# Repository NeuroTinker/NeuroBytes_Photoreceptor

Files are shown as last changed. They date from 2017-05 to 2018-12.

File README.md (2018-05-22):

# NeuroBytes Rod Photoreceptor
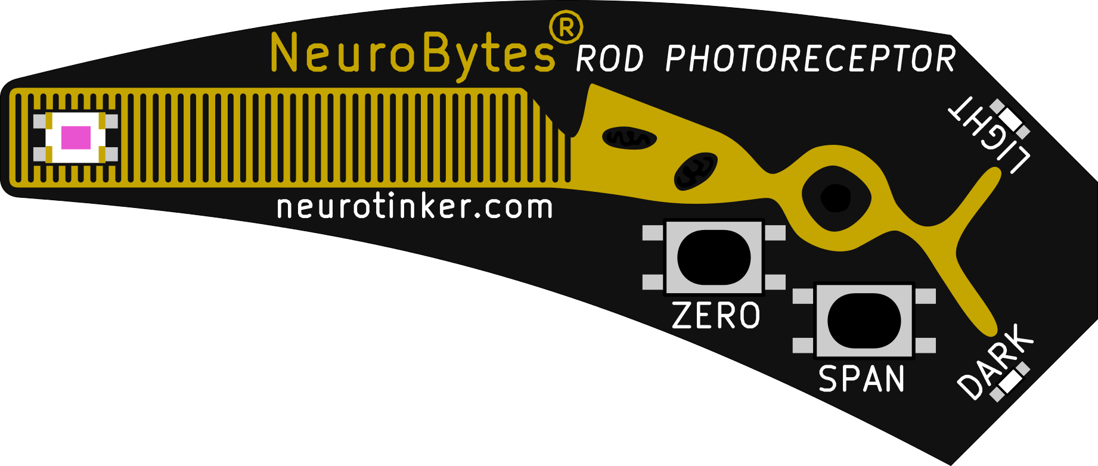
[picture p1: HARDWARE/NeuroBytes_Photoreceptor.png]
NeuroBytes Rod Photoreceptor PCB front

The NeuroBytes Rod Photoreceptor is an open-source hardware neuron simulator designed and sold by [NeuroTinker, LLC](http://www.neurotinker.com/). 

All NeuroBytes products are based on the ST32L0x series of ARM Cortex-M0+ 32-bit microcontrollers. The boards were designed in KiCad and Inkscape and are released under the terms of the Creative Commons Attribution-ShareAlike 4.0 license, available here: http://creativecommons.org/licenses/by-sa/4.0/. The NeuroBytes Rod Photoreceptor is Certified Open Source Hardware as defined by [OSHWA](https://www.oshwa.org), certification number US000108.


OSHWA Certification

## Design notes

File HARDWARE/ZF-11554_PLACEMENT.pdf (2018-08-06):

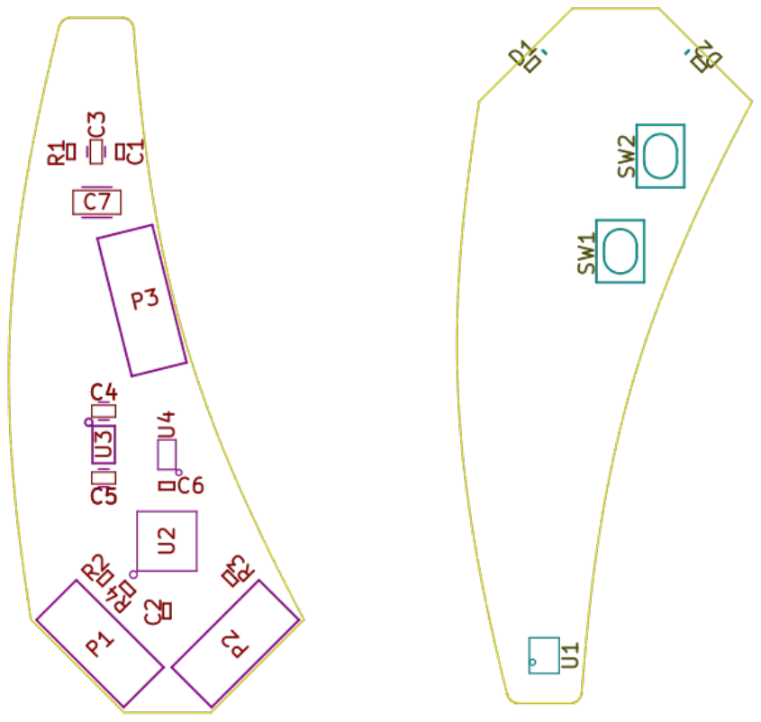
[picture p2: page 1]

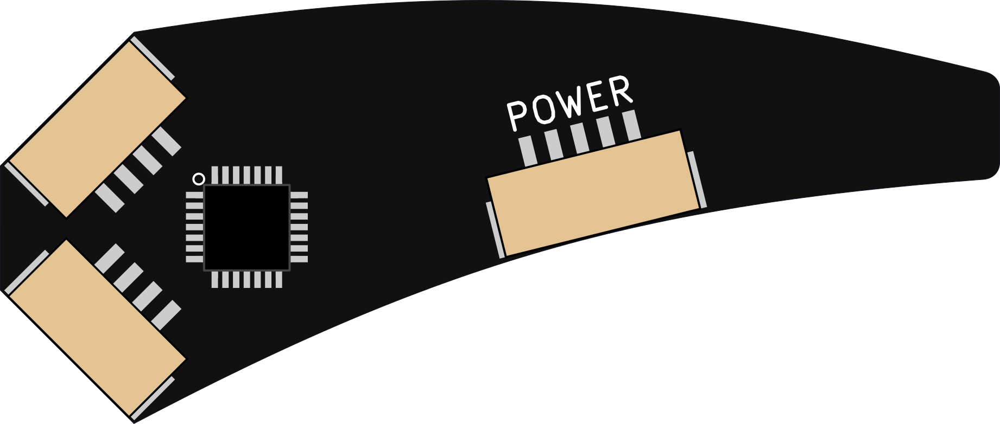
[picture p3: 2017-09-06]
HARDWARE/NeuroBytes_Photoreceptor_back.png

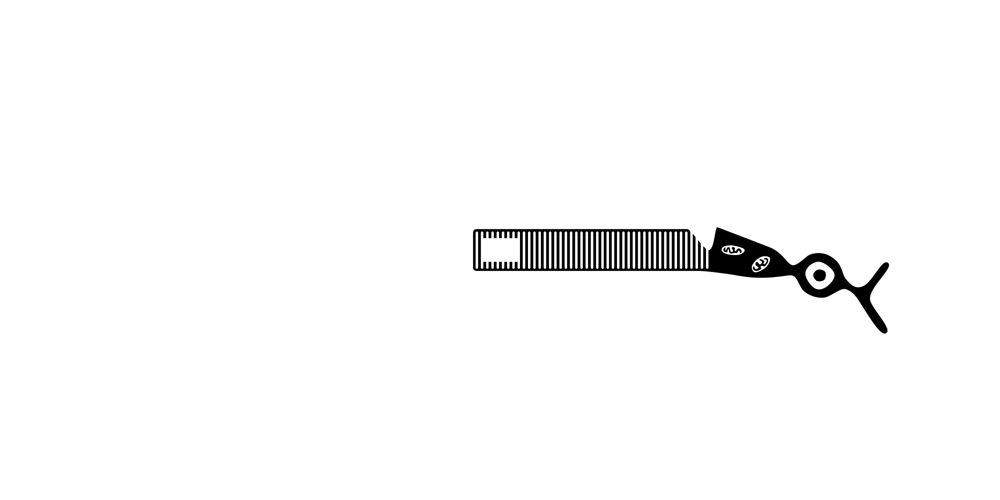
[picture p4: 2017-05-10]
HARDWARE/copper.png

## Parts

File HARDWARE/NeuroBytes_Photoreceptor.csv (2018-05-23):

Ref | Qty | Value | Link | Mfr | Mfr Part # | Package | RoHS | Subs Allowed
C4 C5 C3 | 3 | 1u | https://www.digikey.com/product-detail/en/taiyo-yuden/LMK107B7105KA-T/587-1242-2-ND/930594 | Taiyo Yuden | LMK107B7105KA-T | C0603 | Yes | Yes
C2 C6 C1 | 3 | 0u1 | https://www.digikey.com/product-detail/en/taiyo-yuden/LMK105BJ104KV-F/587-1227-2-ND/930579 | Taiyo Yuden | LMK105BJ104KV-F | C0402 | Yes | Yes
C7 | 1 | 10u | https://www.digikey.com/product-detail/en/taiyo-yuden/EMK316B7106KL-TD/587-2395-2-ND/2178914 | Taiyo Yuden | EMK316B7106KL-TD | C1206 | Yes | Yes
D1 D2 | 2 | LED | https://www.digikey.com/product-detail/en/rohm-semiconductor/SCMP13WBC8W1/846-1111-2-ND/3973663 | Rohm Semiconductor | SCMP13WBC8W1 | 2SMD | Yes | No
P1 P2 | 2 | JST_GH_4-POS | https://www.digikey.com/product-detail/en/jst-sales-america-inc/SM04B-GHS-TB-LF-SN/455-1566-2-ND/807788 | JST | SM04B-GHS-TB(LF)(SN) | SMT | Yes | No
P3 | 1 | JST_GH_5-pos | https://www.digikey.com/product-detail/en/jst-sales-america-inc/SM05B-GHS-TB-LF-SN/455-1567-2-ND/807789 | JST | SM05B-GHS-TB(LF)(SN) | SMT | Yes | No
R2 R3 | 2 | 10 | https://www.digikey.com/product-detail/en/yageo/RC0402FR-0710RL/311-10.0LRTR-ND/726524 | Yageo | RC0402FR-0710RL | R0402 | Yes | Yes
R1 | 1 | 10k | https://www.digikey.com/product-detail/en/yageo/RC0402FR-0710KL/311-10.0KLRTR-ND/726523 | Yageo | RC0402FR-0710KL | R0402 | Yes | Yes
R4 | 1 | JMP | https://www.digikey.com/product-detail/en/yageo/RC0402JR-070RL/311-0.0JRTR-ND/726406 | Yageo | RC0402JR-070RL | R0402 | Yes | Yes
SW2 SW1 | 2 | SW_PB_4term | https://www.digikey.com/product-detail/en/c-k/PTS810-SJM-250-SMTR-LFS/CKN10502TR-ND/4176610 | C&K | PTS810 SJM 250 SMTR LFS | 4SMD | Yes | No
U2 | 1 | STM32L011Gx | http://www.mouser.com/ProductDetail/STMicroelectronics/STM32L011G4U6/ | ST Microelectronics | STM32L011G4U6 | UFQFPN28 | Yes | No
U3 | 1 | 3v3 LDO | https://www.digikey.com/product-detail/en/on-semiconductor/NCP114BSN330T1G/NCP114BSN330T1GOSTR-ND/6560606 | ON Semiconductor | NCP114BSN330T1G | SOT23-5L | Yes | Yes
U1 | 1 | APDS9007 | https://www.digikey.com/product-detail/en/broadcom-limited/APDS-9007-020/516-1719-2-ND/1785429 | Broadcom | APDS-9007-020 | 6SMD | Yes | No
U4 | 1 | RClamp0503F | https://www.digikey.com/product-detail/en/semtech-corporation/RCLAMP0503F.TCT/RCLAMP0503F.TCTTR-ND/5113629 | Semtech Corporation | RCLAMP0503F.TCT | 5-TSSOP | Yes | No
BOM made with KICAD_BOM_WIZARD (https://github.com/HashDefineElectronics/KiCad_BOM_Wizard.git)
Generated Wed 23 May 2018 05:14:28 PM CDT

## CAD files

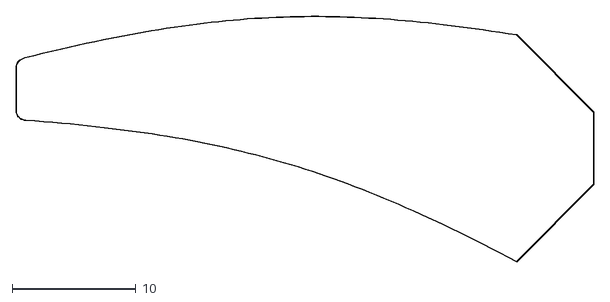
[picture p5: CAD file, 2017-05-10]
HARDWARE/NeuroBytes_Photoreceptor.dxf
46.8 x 19.8

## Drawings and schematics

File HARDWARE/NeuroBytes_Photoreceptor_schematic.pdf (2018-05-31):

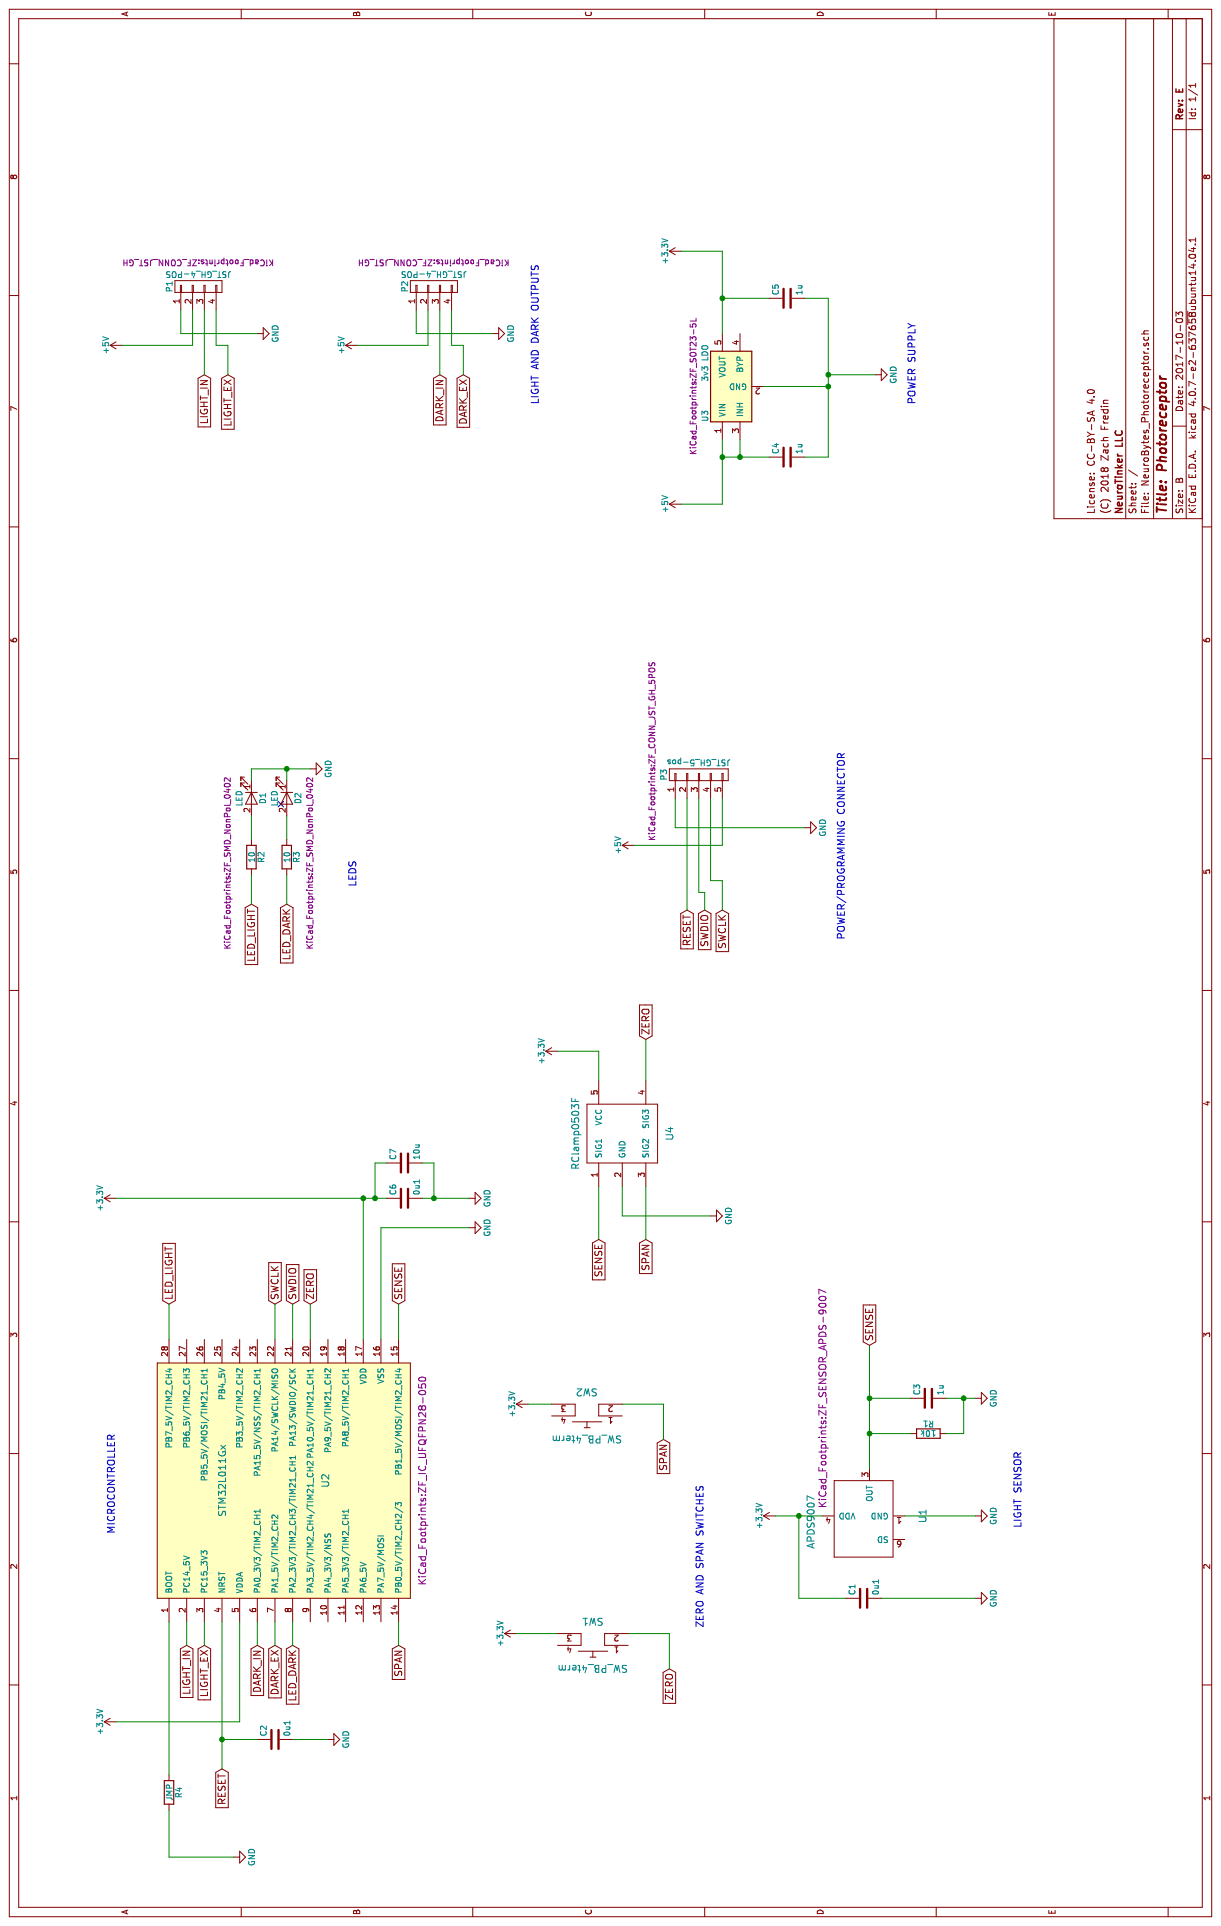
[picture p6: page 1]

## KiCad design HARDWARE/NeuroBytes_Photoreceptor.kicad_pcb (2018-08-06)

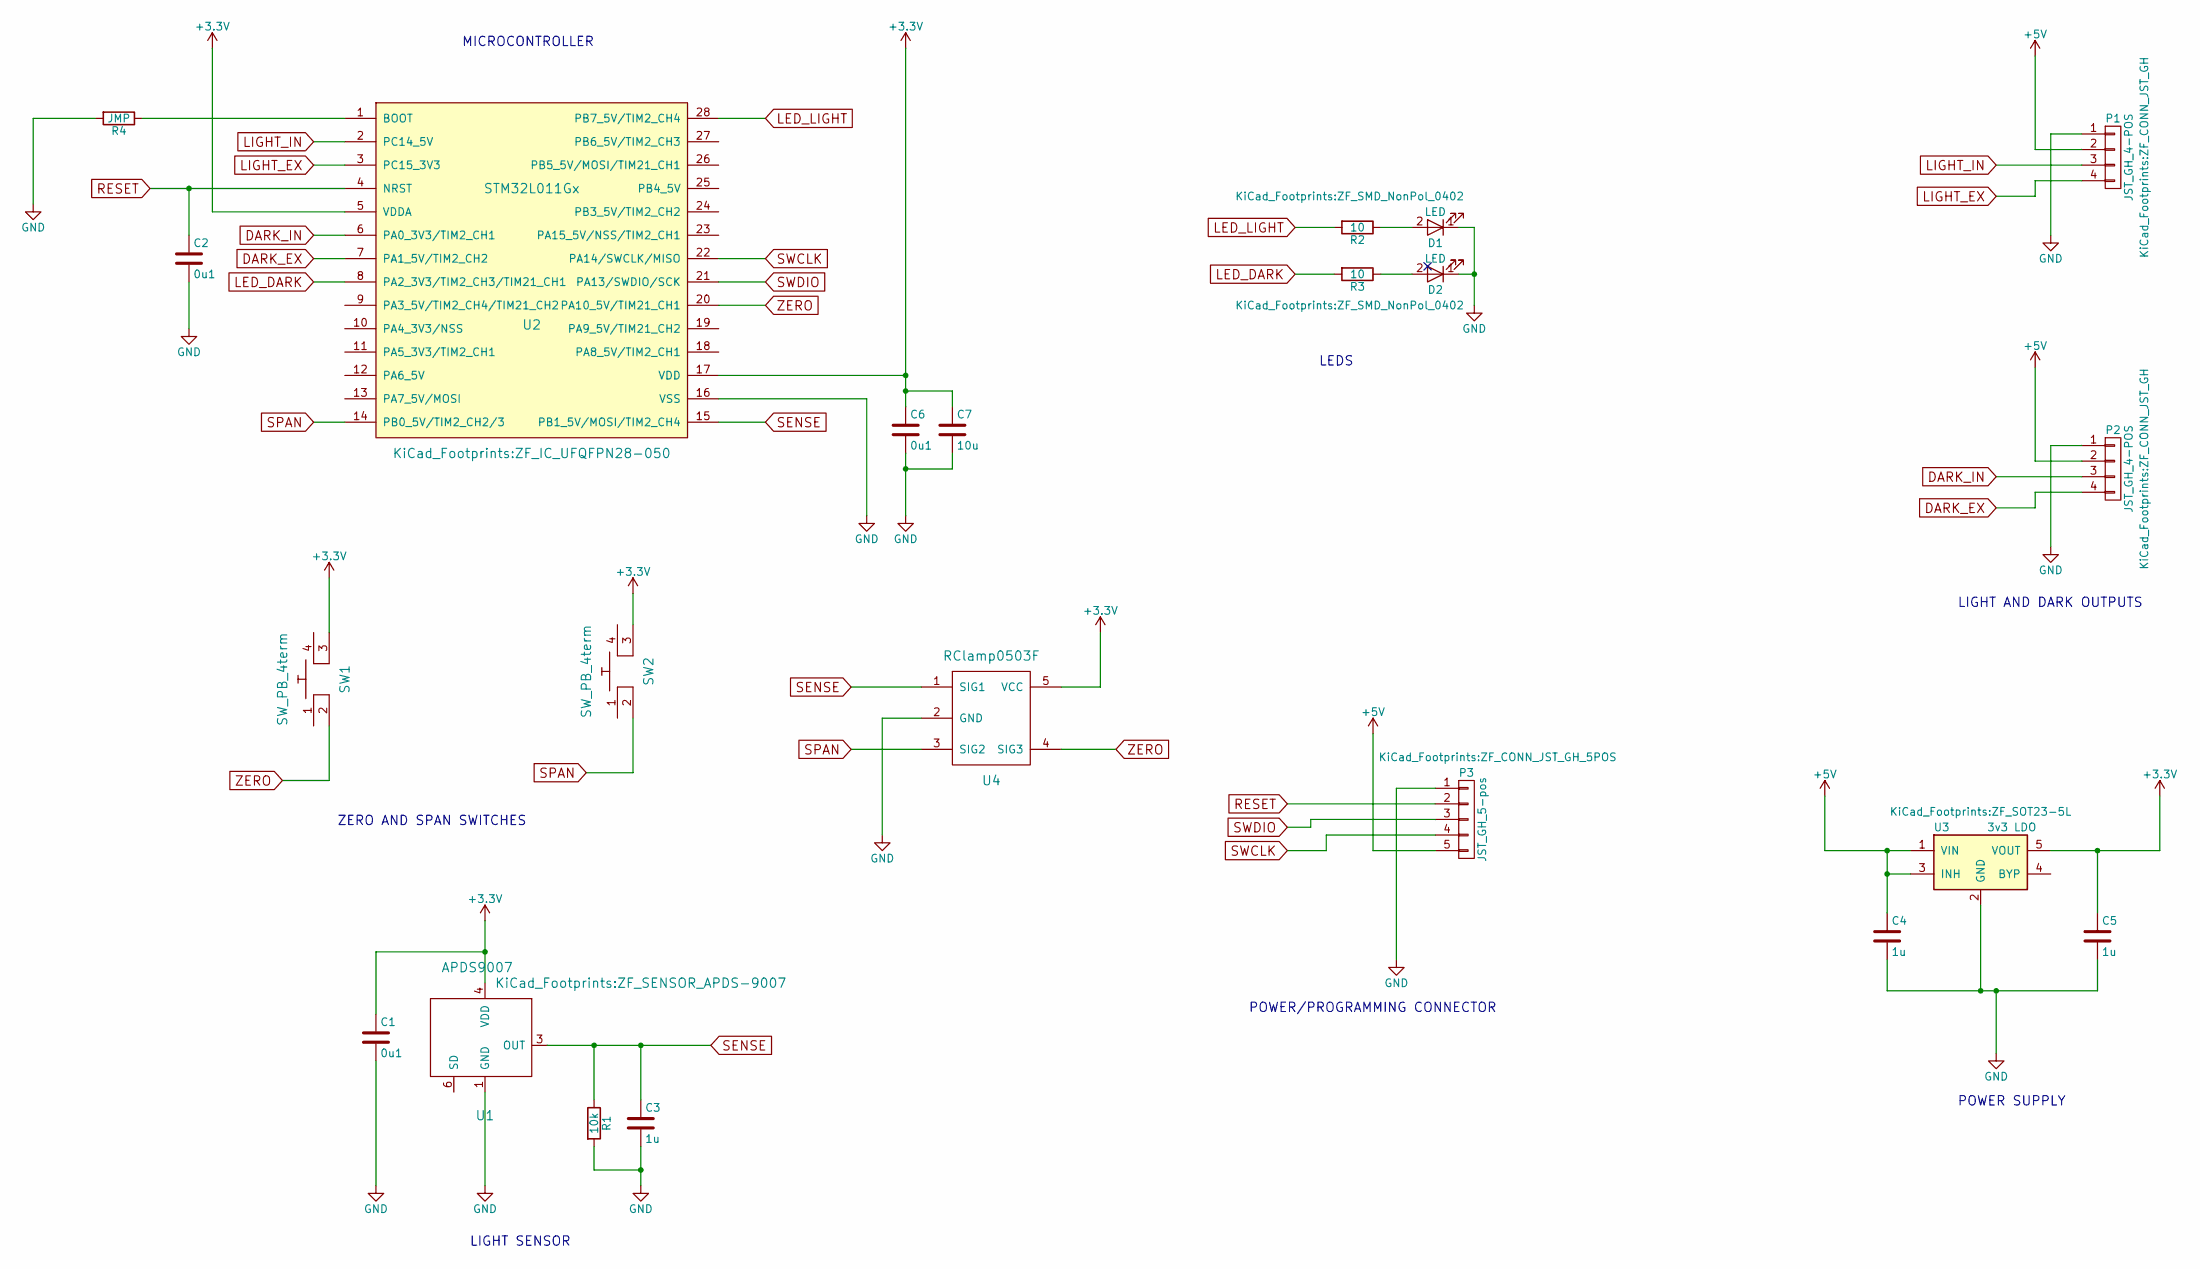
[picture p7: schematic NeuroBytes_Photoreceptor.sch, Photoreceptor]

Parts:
C1, C2, C6: 0u1; ZF_SMD_NonPol_0402_cap; Mfr Part # LMK105BJ104KV-F
C3, C4, C5: 1u; C_0603_HandSoldering; Mfr Part # LMK107B7105KA-T
C7: 10u; C_1206; Mfr Part # EMK316B7106KL-TD
D1, D2: LED; ZF_SMD_NonPol_0402; Mfr Part # SCMP13WBC8W1
P1, P2: JST_GH_4-POS; ZF_CONN_JST_GH; Mfr Part # SM04B-GHS-TB(LF)(SN)
P3: JST_GH_5-pos; ZF_CONN_JST_GH_5POS; Mfr Part # SM05B-GHS-TB(LF)(SN)
R1: 10k; ZF_SMD_NonPol_0402; Mfr Part # RC0402FR-0710KL
R2, R3: 10; ZF_SMD_NonPol_0402; Mfr Part # RC0402FR-0710RL
R4: JMP; ZF_SMD_NonPol_0402; Mfr Part # RC0402JR-070RL
SW1, SW2: SW_PB_4term; ZF_SW_PTS810; Mfr Part # PTS810 SJM 250 SMTR LFS
U1: APDS9007; ZF_SENSOR_APDS-9007; Mfr Part # APDS-9007-020
U2: STM32L011Gx; ZF_IC_UFQFPN28-050; Mfr Part # STM32L011G4U6
U3: 3v3 LDO; ZF_SOT23-5L; Mfr Part # NCP114BSN330T1G
U4: RClamp0503F; ZF_SMD_SOT-353; Mfr Part # RCLAMP0503F.TCT

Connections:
+3V3: C1.1, C5.1, C6.1, C7.1, SW1.3, SW2.3, U1.4 (VDD), U2.5 (VDDA), U2.17 (VDD), U3.5 (VOUT), U4.5 (VCC)
+5V: C4.1, P1.2, P2.2, P3.5, U3.1 (VIN), U3.3 (INH)
DARK_EX: P2.4, U2.7 (PA1_5V/TIM2_CH2)
DARK_IN: P2.3, U2.6 (PA0_3V3/TIM2_CH1)
GND: C1.2, C2.2, C3.2, C4.2, C5.2, C6.2, C7.2, D1.1 (K), D2.1 (K), P1.1, P2.1, P3.1, R1.2, R4.2, U1.1 (GND), U2.16 (VSS), U3.2 (GND), U4.2 (GND)
LED_DARK: R3.2, U2.8 (PA2_3V3/TIM2_CH3/TIM21_CH1)
LED_LIGHT: R2.2, U2.28 (PB7_5V/TIM2_CH4)
LIGHT_EX: P1.4, U2.3 (PC15_3V3)
LIGHT_IN: P1.3, U2.2 (PC14_5V)
unnamed: D1.2 (A), R2.1
unnamed: D2.2 (A), R3.1
unnamed: R4.1, U2.1 (BOOT)
RESET: C2.1, P3.2, U2.4 (NRST)
SENSE: C3.1, R1.1, U1.3 (OUT), U2.15 (PB1_5V/MOSI/TIM2_CH4), U4.1 (SIG1)
SPAN: SW2.2, U2.14 (PB0_5V/TIM2_CH2/3), U4.3 (SIG2)
SWCLK: P3.4, U2.22 (PA14/SWCLK/MISO)
SWDIO: P3.3, U2.21 (PA13/SWDIO/SCK)
ZERO: SW1.2, U2.20 (PA10_5V/TIM21_CH1), U4.4 (SIG3)

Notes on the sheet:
MICROCONTROLLER
ZERO AND SPAN SWITCHES
LIGHT SENSOR
POWER/PROGRAMMING CONNECTOR
LEDS
POWER SUPPLY
LIGHT AND DARK OUTPUTS

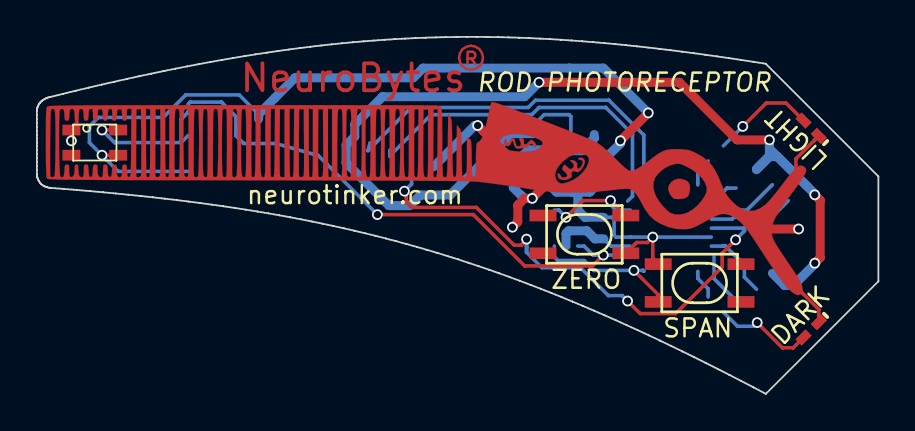
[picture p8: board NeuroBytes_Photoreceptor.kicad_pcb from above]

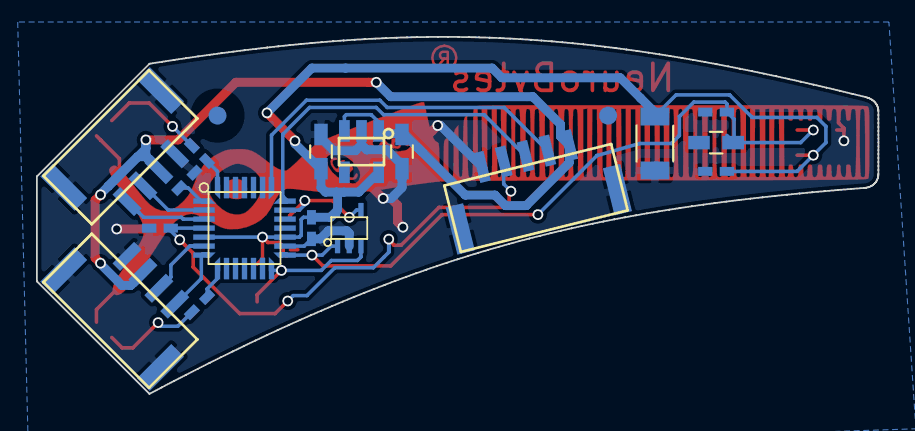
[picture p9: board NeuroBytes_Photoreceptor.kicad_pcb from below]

Board: 2 copper layers, 46.8 x 19.8 mm, 22 parts (17 on the bottom side), 18 nets.

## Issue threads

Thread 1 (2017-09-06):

Prevent zero/span overlap

zakqwy, 2017-09-06:
Deal with case where user tries to set zero point higher than span point.

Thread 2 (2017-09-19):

Intermittent freezing issues

zakqwy, 2017-09-19:
Boards occasionally stop responding to zero/span buttons. Difficult to tell where this issue originates as it often clears on power cycling.

jrwhite, 2017-11-01:
It seems to be an issue with just the light output.

jrwhite, 2017-11-02:
This is fixed in the development branch now. I'll leave this issue open until the fix is merged into master.

jrwhite, 2018-01-30:
The fix is now merged into master. It was an issue with how the gpios on the light axon was being polled and set if you are curious.

Closed 2018-01-30.

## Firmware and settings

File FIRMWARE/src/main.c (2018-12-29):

#include <libopencm3/stm32/rcc.h>
#include <libopencm3/stm32/gpio.h>
#include <libopencm3/stm32/timer.h>
#include <libopencm3/cm3/nvic.h>
#include <libopencm3/cm3/systick.h>
#include <libopencm3/stm32/exti.h>
#include <libopencm3/stm32/adc.h>


#include "comm.h"
#include "HAL.h"

#define MAX_FIRE_TIME	200 
#define	MIN_FIRE_TIME	30	 // 200 ms
#define FIRE_TIME_RANGE	180 // 1200 ms

#define BLINK_TIME			100
#define DATA_TIME			10
#define DEND_PING_TIME		200 // 1000 ms
#define	NID_PING_TIME		200 // 1000 ms
#define SEND_PING_TIME		60
#define BUTTON_PRESS_TIME	2

static uint32_t fingerprint[3] __attribute__((section (".fingerprint"))) __attribute__ ((__used__)) = {
	2,
	1,
	0
};

int temp, output;

int scale10bit(int val, int zero, int span) 
{
	/*	Scales input based on zero and span calibration points. Returns unsigned
		10-bit integer as output (i.e. 0-1023). */

	if (zero < span) 
	{
		if ((val > zero) && (val < span))
		{
			return ((val - zero) * 1023) / (span - zero);
		}
		else if (val <= zero)
		{
			return 0;
		}
		else 
		{
			return 1023;
		}
	}
	else 
	{
		return val;
	}
}


int main(void)
{
	int dark_fire_time = 0;
	int light_fire_time = 0;
	int fire_time = 0;

	uint8_t dark_fire_flag = 0;
	uint8_t light_fire_flag = 0;

	int zero = 450;
	int span = 1450;

	uint16_t	send_ping_time = 0;

	clock_setup();
	gpio_setup();
	tim_setup();
	adc_setup();
	systick_setup(100000); // tick @ 0.1 ms
	
	// setup eeprom

	MMIO32(FLASH_MEM_INTERFACE_BASE + FLASH_PEKEYR) = FLASH_PEKEY1;
	MMIO32(FLASH_MEM_INTERFACE_BASE + FLASH_PEKEYR) = FLASH_PEKEY2;
	MMIO32(FLASH_MEM_INTERFACE_BASE + FLASH_PRGKEYR) = FLASH_PRGKEY1;
	MMIO32(FLASH_MEM_INTERFACE_BASE + FLASH_PRGKEYR) = FLASH_PRGKEY2;

	int eeprom_zero = eepromRead(ZERO_ADDRESS);
	if (eeprom_zero != 0){
		zero = eeprom_zero;
	}
	int eeprom_span = eepromRead(SPAN_ADDRESS);
	if (eeprom_span != 0){
		span = eeprom_span;
	}

	for(;;)
	{
		if (main_tick == 1){
			//gpio_toggle(PORT_LIGHT_OUT, PIN_LIGHT_EX);
			main_tick = 0;

			adc_start_conversion_regular(ADC1);
			while (!(adc_eoc(ADC1)));
			temp = adc_read_regular(ADC1);

			if (readButton(0) > 0)
			{
				if (zero > span) span = temp + 1;
				zero = temp;
				eepromProgram(ZERO_ADDRESS, zero);
			}

			if (readButton(1) > 0)
			{
				if (span < zero) {
					zero = temp;
					span = temp+1;
				} else {
					span = temp;
				}
				eepromProgram(SPAN_ADDRESS, span);
			}

			output = scale10bit(temp, zero, span);

			if (dark_fire_time == 0){
				if (dark_fire_flag == 1){
					dark_fire_flag = 0;
					addWrite(DOWNSTREAM_BUFF, PULSE_MESSAGE);
					downstream_port[downstream_port_i] = 1;
					downstream_port_i += 1;
				}
				dark_fire_time = MIN_FIRE_TIME + ((FIRE_TIME_RANGE * output) / 1023);
				if (dark_fire_time < MAX_FIRE_TIME)
					dark_fire_flag = 1;
			} else {
				dark_fire_time -= 1;
			}

			if (light_fire_time == 0){
				if (light_fire_flag == 1){
					light_fire_flag = 0;
					addWrite(DOWNSTREAM_BUFF, PULSE_MESSAGE);
					downstream_port[downstream_port_i] = 2;
					downstream_port_i += 1;
				}
				light_fire_time = MIN_FIRE_TIME + ((FIRE_TIME_RANGE * (1023-output)) / 1023);
				if (light_fire_time < MAX_FIRE_TIME)
					light_fire_flag = 1;
			} else {
				light_fire_time -= 1;
			}

			setLED(0, (1023 - output) / 5); // dark led
			setLED(1, output / 5); // light led
		

			if (nid_ping_time == 0){
				nid_keep_alive = NID_PING_KEEP_ALIVE;
				nid_pin = 0;
				nid_pin_out = 0;
			}else {
				nid_ping_time -= 1;
			}
				
			if (send_ping_time++ > SEND_PING_TIME){
				addWrite(DOWNSTREAM_BUFF, DEND_PING);
				downstream_port[downstream_port_i] = 3;
				downstream_port_i += 1;
				send_ping_time = 0;
			}

		}
	}
}

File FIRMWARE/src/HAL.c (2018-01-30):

#include "HAL.h"
#include "comm.h"


volatile uint8_t tick = 0;
volatile uint8_t main_tick = 0;
volatile uint8_t read_tick = 0;


uint8_t channel_array[] =  {1, 1, 1};

static const uint16_t gamma_lookup[1024] = {
	/*	Gamma = 2, input range = 0-1023, output range = 0-9600 */
    0,  0,  0,  0,  0,  0,  0,  0,  1,  1,  1,  1,  1,  2,  2,  2,
    2,  3,  3,  3,  4,  4,  4,  5,  5,  6,  6,  7,  7,  8,  8,  9,
    9, 10, 11, 11, 12, 13, 13, 14, 15, 15, 16, 17, 18, 19, 19, 20,
   21, 22, 23, 24, 25, 26, 27, 28, 29, 30, 31, 32, 33, 34, 35, 36,
   38, 39, 40, 41, 42, 44, 45, 46, 48, 49, 50, 52, 53, 54, 56, 57,
   59, 60, 62, 63, 65, 66, 68, 69, 71, 73, 74, 76, 78, 79, 81, 83,
   85, 86, 88, 90, 92, 94, 95, 97, 99,101,103,105,107,109,111,113,
  115,117,119,121,123,126,128,130,132,134,137,139,141,143,146,148,
  150,153,155,157,160,162,165,167,170,172,175,177,180,182,185,188,
  190,193,196,198,201,204,206,209,212,215,218,220,223,226,229,232,
  235,238,241,244,247,250,253,256,259,262,265,268,271,275,278,281,
  284,287,291,294,297,301,304,307,311,314,317,321,324,328,331,335,
  338,342,345,349,352,356,360,363,367,371,374,378,382,386,389,393,
  397,401,405,408,412,416,420,424,428,432,436,440,444,448,452,456,
  460,464,469,473,477,481,485,489,494,498,502,507,511,515,520,524,
  528,533,537,542,546,551,555,560,564,569,573,578,583,587,592,596,
  601,606,611,615,620,625,630,634,639,644,649,654,659,664,669,674,
  679,684,689,694,699,704,709,714,719,724,729,735,740,745,750,756,
  761,766,771,777,782,788,793,798,804,809,815,820,826,831,837,842,
  848,853,859,865,870,876,882,887,893,899,904,910,916,922,928,933,
  939,945,951,957,963,969,975,981,987,993,999,1005,1011,1017,1023,1029,
  1036,1042,1048,1054,1060,1067,1073,1079,1086,1092,1098,1105,1111,1117,1124,1130,
  1137,1143,1150,1156,1163,1169,1176,1182,1189,1195,1202,1209,1215,1222,1229,1236,
  1242,1249,1256,1263,1269,1276,1283,1290,1297,1304,1311,1318,1325,1332,1339,1346,
  1353,1360,1367,1374,1381,1388,1395,1402,1410,1417,1424,1431,1439,1446,1453,1460,
  1468,1475,1482,1490,1497,1505,1512,1520,1527,1534,1542,1550,1557,1565,1572,1580,
  1587,1595,1603,1610,1618,1626,1634,1641,1649,1657,1665,1673,1680,1688,1696,1704,
  1712,1720,1728,1736,1744,1752,1760,1768,1776,1784,1792,1800,1808,1817,1825,1833,
  1841,1849,1858,1866,1874,1882,1891,1899,1907,1916,1924,1933,1941,1949,1958,1966,
  1975,1983,1992,2001,2009,2018,2026,2035,2044,2052,2061,2070,2078,2087,2096,2105,
  2114,2122,2131,2140,2149,2158,2167,2176,2185,2194,2202,2211,2220,2230,2239,2248,
  2257,2266,2275,2284,2293,2302,2312,2321,2330,2339,2349,2358,2367,2377,2386,2395,
  2405,2414,2424,2433,2442,2452,2461,2471,2480,2490,2500,2509,2519,2528,2538,2548,
  2557,2567,2577,2586,2596,2606,2616,2626,2635,2645,2655,2665,2675,2685,2695,2705,
  2715,2725,2735,2745,2755,2765,2775,2785,2795,2805,2815,2826,2836,2846,2856,2866,
  2877,2887,2897,2908,2918,2928,2939,2949,2959,2970,2980,2991,3001,3012,3022,3033,
  3043,3054,3065,3075,3086,3097,3107,3118,3129,3139,3150,3161,3172,3182,3193,3204,
  3215,3226,3237,3248,3258,3269,3280,3291,3302,3313,3324,3335,3347,3358,3369,3380,
  3391,3402,3413,3425,3436,3447,3458,3470,3481,3492,3503,3515,3526,3538,3549,3560,
  3572,3583,3595,3606,3618,3629,3641,3652,3664,3676,3687,3699,3711,3722,3734,3746,
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

void sys_tick_handler(void)
{
	
	if (++tick >= 50){
		main_tick = 1;
		tick = 0;
	}
	
	if (read_tick++ >= 2){
		writeBit();
		read_tick = 0;
	}
	
	//readBit(read_tick);
	
}

void systick_setup(int freq) 
{
	systick_set_clocksource(STK_CSR_CLKSOURCE_EXT);
    STK_CVR = 0;
    //systick_set_reload(2 * xms);
	systick_set_reload(180); //180
    systick_counter_enable();
    systick_interrupt_enable();
}

void clock_setup(void)
{
	/*	Set clock source to 16 MHz High-Speed Internal oscillator and turn it on */
	rcc_set_sysclk_source(RCC_HSI16);
	rcc_osc_on(RCC_HSI16);
}

void gpio_setup(void)
{
	/*	Enable GPIO clocks */
	rcc_periph_clock_enable(RCC_GPIOA);
	rcc_periph_clock_enable(RCC_GPIOB);
	rcc_periph_clock_enable(RCC_GPIOC);

	rcc_peripheral_enable_clock(&RCC_APB2ENR, RCC_APB2ENR_SYSCFGEN); // clk for exti 

	/*	Set up LED pins:
		Alternative Function Mode with no pullup/pulldown
		Output options: push-pull, high speed
		PIN_LED_LIGHT (PB7): AF5, TIM2_CH4
		PIN_LED_DARK (PA2): AF2, TIM2_CH3 */
	gpio_mode_setup(PORT_LED_LIGHT, GPIO_MODE_AF, GPIO_PUPD_NONE, PIN_LED_LIGHT);
	gpio_mode_setup(PORT_LED_DARK, GPIO_MODE_AF, GPIO_PUPD_NONE, PIN_LED_DARK);
	gpio_set_output_options(PORT_LED_LIGHT, GPIO_OTYPE_PP, GPIO_OSPEED_HIGH, PIN_LED_LIGHT);
	gpio_set_output_options(PORT_LED_DARK, GPIO_OTYPE_PP, GPIO_OSPEED_HIGH, PIN_LED_DARK);
	gpio_set_af(PORT_LED_LIGHT, GPIO_AF5, PIN_LED_LIGHT);
	gpio_set_af(PORT_LED_DARK, GPIO_AF2, PIN_LED_DARK);

	/*	Set up ADC input */
	gpio_mode_setup(PORT_SENSE, GPIO_MODE_ANALOG, GPIO_PUPD_NONE, PIN_SENSE);

	/*	Set up button inputs */
	gpio_mode_setup(PORT_ZERO, GPIO_MODE_INPUT, GPIO_PUPD_PULLDOWN, PIN_ZERO);
	gpio_mode_setup(PORT_SPAN, GPIO_MODE_INPUT, GPIO_PUPD_PULLDOWN, PIN_SPAN);

	// Set up axons
	/*
	gpio_mode_setup(PORT_DARK_OUT, GPIO_MODE_OUTPUT, GPIO_PUPD_PULLDOWN, PIN_DARK_OUT_EX);
	gpio_mode_setup(PORT_DARK_OUT, GPIO_MODE_OUTPUT, GPIO_PUPD_PULLDOWN, PIN_DARK_OUT_IN);
	gpio_mode_setup(PORT_LIGHT_OUT, GPIO_MODE_OUTPUT, GPIO_PUPD_PULLDOWN, PIN_LIGHT_EX);
	gpio_mode_setup(PORT_LIGHT_OUT, GPIO_MODE_OUTPUT, GPIO_PUPD_PULLDOWN, PIN_LIGHT_IN);
	*/
	setAsInput(PORT_DARK_OUT, PIN_DARK_IN);
	setAsInput(PORT_LIGHT_OUT, PIN_LIGHT_IN);
	setAsOutput(PORT_DARK_OUT, PIN_DARK_EX);
	setAsOutput(PORT_LIGHT_OUT, PIN_LIGHT_EX);

	//nvic_enable_irq(NVIC_EXTI0_1_IRQ);
	//nvic_enable_irq(NVIC_EXTI2_3_IRQ);
	//nvic_enable_irq(NVIC_EXTI4_15_IRQ);

	nvic_set_priority(NVIC_EXTI0_1_IRQ, 0);
	nvic_set_priority(NVIC_EXTI2_3_IRQ, 0);
	nvic_set_priority(NVIC_EXTI4_15_IRQ, 0);
}

void setAsInput(uint32_t port, uint32_t pin)
{
	// setup gpio as an input pin
	gpio_mode_setup(port, GPIO_MODE_INPUT, GPIO_PUPD_PULLDOWN, pin);

	// setup interrupt for the pin going high
	exti_select_source(pin, port);
	exti_set_trigger(pin, EXTI_TRIGGER_RISING);
	exti_enable_request(pin);
	exti_reset_request(pin);
}

void setAsOutput(uint32_t port, uint32_t pin)
{
	// disable input interrupts
	exti_disable_request(pin);

	// setup gpio as an output pin. pulldown
	gpio_mode_setup(port, GPIO_MODE_OUTPUT, GPIO_PUPD_PULLDOWN, pin);
}

void exti0_1_isr(void)
{
	// interrupt handler for pin 0 (dark in)
	if ((EXTI_PR & PIN_DARK_IN) != 0){
		active_input_pins[0] = PIN_DARK_IN;
		EXTI_PR |= PIN_DARK_IN; // clear interrupt flag
	}
}

void exti14_15_isr(void)
{
	// interrupt handler for pin 14 (light in)
	if ((EXTI_PR & PIN_LIGHT_IN) != 0){
		active_input_pins[1] = PIN_LIGHT_IN;
		EXTI_PR |= PIN_LIGHT_IN; // clear interrupt flag
	}
}
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

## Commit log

2017-03-23 Added first hardware files (PCB, schematic, graphics). Two versions on layout, stubby and regular. Note that BOOT0 isn't connected to GND, so it must be bodged!
    [photoreceptor-stubby.dxf, photoreceptor.csv, photoreceptor.dxf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]
2017-03-24 Demo code to test the ADC, zero/span functionality, and general light sensor characteristics. LEDs fade (PWM via TIM2) inversely based on ambient light.
2017-05-10 Iterated hardware design to incorporate several new features: (1) PCB outline no longer in line with cell wall; rather, entire photoreceptor is displayed on front in copper, and PCB outline is design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
    [NeuroBytes_Photoreceptor.csv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]
2017-05-10 Moved SENSE line from PB6 to PB1 so it's now on an ADC line (ADC9). Bodging prototypes.
    [NeuroBytes_Photoreceptor.kicad_pcb, NeuroBytes_Photoreceptor.sch]
2017-05-10 Reloaded ground pour to take moved SENSE line into account.
    [NeuroBytes_Photoreceptor.kicad_pcb]
2017-05-15 added schematic library submodule
2017-05-15 Updated KiCad project file to reference library submodule
    [NeuroBytes_Photoreceptor.sch]
2017-05-16 Updated Gerber files. Added BOM. Added component values to schematic. Added fiducials.
    [NeuroBytes_Photoreceptor-B.Cu.gbr, NeuroBytes_Photoreceptor-B.Fab.gbr, NeuroBytes_Photoreceptor-B.Mask.gbr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]
2017-05-31 Updated swith footprint.
    [NeuroBytes_Photoreceptor-B.Cu.gbr, NeuroBytes_Photoreceptor-B.Fab.gbr, NeuroBytes_Photoreceptor-B.Mask.gbr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]
2017-05-31 Another switch footprint update
    [NeuroBytes_Photoreceptor.kicad_pcb, NeuroBytes_Photoreceptor.sch]
2017-05-31 minor PCB updates to improve manufacturability (sp?)
    [NeuroBytes_Photoreceptor.csv, NeuroBytes_Photoreceptor.kicad_pcb]
2017-07-25 added fingerprint
2017-08-10 added .fingerprint
2017-08-11 updated fingerprint
2017-08-11 Changed to 5-pin JST GH connector for programming and power. Added POWER label. Minor routing changes.
    [NeuroBytes_Photoreceptor.kicad_pcb, NeuroBytes_Photoreceptor.sch]
2017-08-11 add fingerprint
2017-08-11 changed fingerprint address
2017-08-28 added kicad fonts to *.svg. exported board render.
2017-09-11 fixed simultaneous excitation issue
    [comm.c]
2017-09-22 deleted flash.gdb from FIRMWARE directory. added photoreceptor board export.
2017-09-22 regenerated and loaded netlist. deleted old Gerbers and other misc files.
    [NeuroBytes_Photoreceptor-B.Cu.gbr, NeuroBytes_Photoreceptor-B.Fab.gbr, NeuroBytes_Photoreceptor-B.Mask.gbr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]
2017-09-22 updated component descriptions. reloaded netlist. minor PCB updates. fresh *.csv export.
    [NeuroBytes_Photoreceptor.csv, NeuroBytes_Photoreceptor.kicad_pcb, NeuroBytes_Photoreceptor.sch]
2017-10-03 minor page layout updates
    [NeuroBytes_Photoreceptor.kicad_pcb, NeuroBytes_Photoreceptor.sch]
2017-11-02 switched to systick and fixed stalling
    [HAL.c, comm.c, comm.h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]
2017-11-30 updated license, readme, and PCB. CC-BY-SA 4.0
    [NeuroBytes_Photoreceptor.kicad_pcb]
2018-02-13 schematic library update
2018-02-13 added ESD protection. updated title block. minor routing changes.
    [NeuroBytes_Photoreceptor.kicad_pcb, NeuroBytes_Photoreceptor.sch]
2018-05-23 generated fab files. generated BOM.
    [NeuroBytes_Photoreceptor-B.Cu.gbr, NeuroBytes_Photoreceptor-B.Mask.gbr, NeuroBytes_Photoreceptor-B.Paste.gbr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]
2018-05-31 exported schematic *.pdf
2018-08-06 updated footprints to include B.Fab outlines. minor routing changes. re-generated Gerbers. added placement pdf.
    [NeuroBytes_Photoreceptor-B.Cu.gbr, NeuroBytes_Photoreceptor-B.Fab.gbr, NeuroBytes_Photoreceptor-B.Mask.gbr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]
2018-08-08 regen drill file
    [NeuroBytes_Photoreceptor.drl]

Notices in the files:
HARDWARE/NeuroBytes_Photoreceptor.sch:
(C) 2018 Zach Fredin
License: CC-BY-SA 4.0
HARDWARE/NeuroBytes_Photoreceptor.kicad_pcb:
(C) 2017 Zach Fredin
